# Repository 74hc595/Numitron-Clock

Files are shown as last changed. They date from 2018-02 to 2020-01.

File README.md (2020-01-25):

# IV-19 Numitron Alarm Clock

This is a digital alarm clock that uses Soviet surplus IV-19 (ИВ-19) incandescent ["numitron"](http://www.decadecounter.com/vta/tubepage.php?item=10) displays. 

**[Video overview](https://www.youtube.com/watch?v=N-rBARzu5Fk)**

## Features

The feature set is similar to that of my [Panaplex clock](https://github.com/74hc595/Panaplex-Clock):

- Six digit display (hours/minutes/seconds and month/day/year)
- Powered from a 5V USB charger
- Coin cell battery backup keeps time when unplugged
- Highly accurate oscillator; keeps time within ±3 parts per million
- Piezo beeper alarm
- Automatic leap year correction up to 2099
- Automatic daylight saving time correction (US) up to 2099
- 4-level brightness control
- Sleep mode: can be configured to keep the display blanked and only show the time for a few seconds at the press of a button

## Background

Unlike Nixie tubes, a numitron is not filled with gas and doesn't require high voltage; each segment is literally just an incandescent filament, same as you'd find in a light bulb.

They were a technological stopgap between nixie tubes and LEDs. They also seem to have been used extensively in avionics equipment. (and in the climax of the movie _WarGames_!) I remember seeing them on fuel pumps in the late 1980s.

I found these particular displays on eBay and despite their insane price (US$25 each!) I bought them because of their very uncommon [nine-segment layout](https://en.wikipedia.org/wiki/Nine-segment_display). I've only found evidence of two other people using these displays for projects—and I had to resort to a [Yandex image search](https://yandex.ru/images/search?text=ИВ-20)!

I was able to find a scan of the original Russian datasheet on [Dieter's tube data site](http://www.tube-tester.com/sites/nixie/dat_arch.htm). I've included it in this repo, along with a rough Google translation.

## Hardware

The design is fairly straightforward. Numitrons don't multiplex well, so all 60 segments are direct-driven. They don't require high voltage (I'm driving them with a 3.7V supply) so I used four [STP16CP05](https://www.mouser.com/ProductDetail/STMicroelectronics/STP16CP05MTR/?qs=sGAEpiMZZMvsUbCbgzcXuExUir1Co9YI) constant-current shift register drivers. The segments draw about 22 mA _each_—over an order of magnitude more than LED displays. Multiply that by 60, then multiply that by 3.7, and you'll find that the display draws 4.8 watts with all segments illuminated!

For the brains, I use an [NXP LPC811](https://www.nxp.com/products/processors-and-microcontrollers/arm-based-processors-and-mcus/lpc-cortex-m-mcus/lpc800-series-cortex-m0-plus-mcus/low-cost-microcontroll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)—a relatively bare-bones Arm Cortex-M0+ microcontroller.

Like the Panaplex clock, the enclosure design is an homage to the wood-grain Heathkit clocks from the 1970s, like the [GC-1005](http://tubetime.us/index.php/2012/04/). (Hi Eric!) It's made of 1/8" laser-cut walnut hardwood. The faceplate is transparent 1/8" acrylic, also laser-cut. Unlike neon/Nixie tubes, which emit a very specific wavelength of orange light, the numitron filaments give off a wide spectrum of light, so you can use any color filter you want! I made transparent red, green, and blue faceplates. The blue is best in my opinion—the digits are a deep turquoise color that I haven't been able to photograph successfully.

## Operation

There is a column of three pushbuttons on the back. From top to bottom, they are labeled `+` (Plus), `◉` (Enter), and `−` (Minus).

#### Time display

At the 26th second of even minutes, the date is shown (month/day/year, sorry rest-of-the-world) for 5 seconds. If the backup battery is failing or not present, the display will also briefly show `BAT LO`.

During time display, each button has two functions:

- **Press** `+`: change brightness
- **Hold** `+`: enter sleep mode
- **Press** `◉`: set alarm (see below)
- **Hold** `◉`: set time (see below)
- **Press** `−`: show date for 5 seconds
- **Hold** `−`: enter options menu (see below)

### Setting the time

The hours should be flashing. Use `+`/`−` to change the hour. Press `◉` to advance to the minutes and use `+`/`−` to change the minute. Pressing `◉` finalizes the time, resetting the seconds to :00 and returning you to the normal time display.

Hold `◉` to cancel and return to the normal time display. Any changes to the time are discarded.

### Setting the alarm

The letter `A.` should be flashing. Pressing `+` or `−` toggles the alarm on and off. When the alarm is active, the decimal point of the rightmost digit will illuminate.

Press `◉` to advance to the hours. Use `+`/`−` to change the hour. Press `◉` to advance to the minutes and use `+`/`−` to change the minute.

Hold `◉` to cancel and return to the normal time display. Any changes to the alarm time are discarded.

### Silencing the alarm

When the alarm is going off, hold any button to silence it.

### Alarms and loss of power

The alarm time and state are saved in battery-backed memory. If power is lost, but restored before the alarm's set time, the alarm will go off normally. If power is restored _after_ the alarm's set time, the alarm will _not_ go off.

### Options menu

Pressing `+` and `−` cycle through the menu options:

- `zzz` - turn sleep mode on/off (`Y`/`N`)
- `DATE>` - press `◉` to set date (see below)
- `A.DST` - turn automatic daylight saving time correction on/off (`Y`/`N`)
- `FONT` - switch between 9-segment font (`1`) and 7-segment font (`2`) for time/date display
- `CYCL` - turn date cycling on even minutes on/off (`Y`/`N`)
- `STYLE>` - press `◉` to change time display style (see below)
- Backup battery status: will show `BAT OK` or `BAT LO`
- Firmware version, e.g. `Ver 1.2`
- `DONE>` - press `◉` to return to normal time display

Hold `◉` to cancel and return to the normal time display.

### Setting the date

The month should be flashing. Use `+`/`−` to change the month. Press `◉` to advance to the date and use `+`/`−` to change the date. Press `◉` to advance to the year and use `+`/`−` to change the year. Press `◉` to finalize the date.

Hold `◉` to cancel and return to the menu. Any changes to the date are discarded.

### Setting the display style

Press `+` and `−` to cycle through four time display options:

- `hh.mm.ss` (hour, minute, second)
- `hh.mm` (hour and minute only)
- `h.mm a` (12-hour display with hour, minute, and AM/PM indicator. `◿`=AM, `◸`=PM)
- `hh . mm` (hour and minute only)

Press `◉` to return to the menu.

### Flashing new firmware

Cycle through menu options until the firmware version is displayed. Hold `+` to enter the bootloader. The display will show `---`. You can now connect a 5V FTDI cable and use the `lpc21isp` utility to flash a new firmware image.

To return to normal operation, disconnect and reconnect the power.

## Power considerations

The clock can draw up to 1.5A during operation. It's recommended that you use a high-quality USB power adapter (10 watts or higher), and a "28/24 AWG" USB mini-B cable.

## Version history

### Version 1.2 (March 21, 2019)

- Reduced number of brightness levels to 4.
- Added option to change the number font to one that uses a "standard" 7-segment layout which does not use the diagonal segments. Some may find this more readable.

### Version 1.1 (April 29, 2018)

- 12-hour display style added. Selectable from the `STYLE>` menu. When enabled, 12-hour format with AM/PM indicator (`◿`=AM, `◸`=PM) is used when displaying the time, setting the time, and setting the alarm.

### Version 1.0 (February 11, 2018)

- Initial release

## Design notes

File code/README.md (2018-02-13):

# IV-19 Numitron Clock Firmware

### Requirements
- GNU `arm-none-eabi-gcc` toolchain
- `lpc21isp` v1.97 (available from Homebrew on a Mac or from [GitHub](https://github.com/capiman/lpc21isp))
- 5V FTDI USB-serial cable

### To build
- Run `make`.
- Connect the FTDI cable to the 6-pin header on the clock (black wire indicated by a pointing triangle).
- Power on the clock while holding top button (SW1). Display should not illuminate.
- Run `make flash`.

### Hardware
The clock uses the [NXP LPC811](https://www.nxp.com/products/processors-and-microcontrollers/arm-based-processors-and-mcus/lpc-cortex-m-mcus/lpc800-series-cortex-m0-plus-mcus/low-cost-microcontroll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), a no-frills Arm Cortex-M0+ microcontroller with 8KB flash and 2KB RAM. Despite its limited peripheral set, (it doesn't even have an ADC) it gets the job done. I chose this chip for 3 reasons:

1. It has a serial bootloader in ROM and can be programmed with just an FTDI cable
2. The peripherals are simple enough that vendor SDK code isn't required
3. I had a couple of them lying around

The real-time clock is the [NXP PCF2129](https://www.nxp.com/products/analog/signal-chain/real-time-clocks/rtcs-with-temperature-compensation/accurate-rtc-with-integrated-quartz-crystal-for-industrial-appli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). It has a built-in temperature compensated oscillator with an advertised accuracy of ±3 ppm. Its feature set is similar to that of Maxim's high accurary real-time clocks like the [DS3234](https://www.mouser.com/ProductDetail/Maxim-Integrated/DS3234S?qs=sGAEpiMZZMuuBt6TL7D%2f6Oew70i91ENb), but it's a [third](https://www.mouser.com/ProductDetail/NXP-Semiconductors/PCF2129AT-2518?qs=sGAEpiMZZMvocn3OtlEZq6VFh71YhKpQ) of the price.

### Code notes

The driver and utility functions are written in C and the application code is C++11. 

The display state is encoded in a 64-bit integer. Since the display only has 60 segments (each digit has 10 segments; nine plus decimal point), 4 bits are unused. The mapping from bits to segments is irregular; the bit assignment was chosen to simplify the circuit layout. Each 32-bit word holds the data for 30 segments (3 digits) with 2 bits unused.

For ease of programming, application code treats the display as six 16-bit halfwords, one per digit, with the lower 10 bits mapping to segments `a` through `i` plus decimal point. The function `three_digits_packed()` converts three 16-bit values to the particular 32-bit internal representation. And it's written in assembly because I couldn't help myself. :)

SysTick is the only interrupt used. It runs at a rate of 480 Hz. On each iteration, the segment pattern is shifted out to the drivers. This handles the segment preheating and PWM dimming. 480 Hz allows for eight levels of brightness without visible flicker.

One oddity is that the display shift registers are always cleared (by shifting out 64 zeros) before shifting out the segment pattern. I was encountering a weird issue where the leftmost 3 digits would glitch out occasionally. I assumed this was due to a timing glitch, but rather than tracking down the root cause, I found that the glitch disappeared if the shift registers were zeroed first. So I hacked that up and moved on. :)

Every 8 ticks (60 Hz) the button state is read and the `/RTC_INT` line is checked. The PCF2129AT is configured to pulse `/RTC_INT` low once per second. The pin change interrupt is used to detect falling edges, but to keep the code simple and deterministic, I poll the interrupt flag rather than use the actual asynchronous interrupt.

At any time, only one "app" has control of the display. An "app" can be thought of as a state in a state machine. Each app exposes two public methods. `init()` is called when an app becomes active. `update()` is called at 60 Hz with a 32-bit bitmask of asserted input events. It returns a pointer to another app, or `NULL` if no state change is required. The methods `timeout()` and `flash_mask()` are used by the main loop to handle common logic for apps that "time out" after a period of no input and apps that want to flash portions of the display.

As much as possible, all date arithmetic is performed in binary coded decimal.

The PCF2129 does not have dedicated battery-backed SRAM for storing settings. However, since the clock doesn't need the day and weekday alarms, I can use them as 10 bits of general-purpose battery-backed storage, saving me from using a more expensive RTC or using the battery to keep the microcontroller powered while unplugged.

The SCTimer peripheral is used to generate two complementary square waves which drive the piezo beeper.

### Special thanks

Kevin Townsend for his [LPC810 base code](https://github.com/microbuilder/LPC810_CodeBase).

James Coxon for the only [reasonable SCTimer PWM example](https://github.com/jamescoxon/LPC812/blob/master/src/pwm.c) I could find online.

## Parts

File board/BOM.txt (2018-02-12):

IV-19 Numitron Clock Bill of Materials
======================================

BT1                     12mm coin cell holder, SMD, Linx BAT-HLD-012-SMT
C1, C2, C3              0.1uF multilayer ceramic capacitor, 16V or higher, 0603
C4                      1uF X7R multilayer ceramic capacitor, 16V or higher, 0603
C5                      2.2uF X7R multilayer ceramic capacitor, 16V or higher, 0603
C6                      10uF multilayer ceramic capacitor, 25V, 1206, AVX 12063C106KAT2A
C7                      10uF tantalum capacitor, 20V, 1210, AVX TAJB106K020RNJV
J101                    1x31 0.1" straight header pin
J102                    1x30 0.1" straight header pin
J201                    1x31 0.1" straight header socket
J202                    1x30 0.1" straight header socket
J204                    1x6 0.1" right-angle header pin
J205                    USB-B mini socket, straight, Amphenol UE25BE5510H
N1, N2, N3, N4, N5, N6  IV-19 numitron tube (eBay)
                        Pin sockets: Mill-Max 0327-0-15-15-34-27-10-0, qty 60
R1, R2, R3, R4, R5      910 ohm resistor, 1/8 watt, 1206
R6                      240 ohm resistor, 1/8 watt, 1206
R7                      470 ohm resistor, 1/8 watt, 1206
SW1, SW2, SW3           Tactile switch, 6mm, through hole, 13mm actuator
U1, U2, U3, U4          Display driver, ST STP16CP05MTR
U5                      Cortex-M0+ microcontroller, NXP LPC811M001JDH16J
U6                      Real-time clock, NXP PCF2129AT/2,518
U7                      3.3V LDO regulator, TI TPS70933DBVR
U8                      3A adjustable LDO regulator, TI LM1085ISX-ADJ/NOPB
Y1                      Piezo sounder, Murata PKLCS1212E2000-R1

(J203 omitted)

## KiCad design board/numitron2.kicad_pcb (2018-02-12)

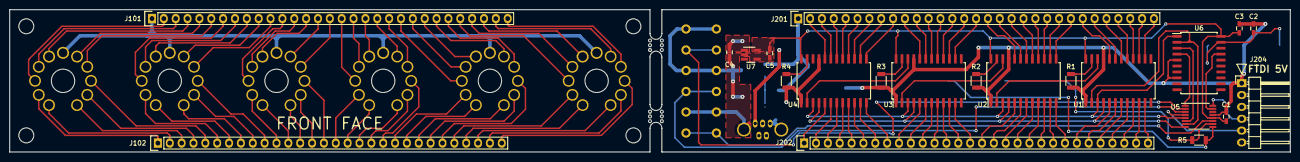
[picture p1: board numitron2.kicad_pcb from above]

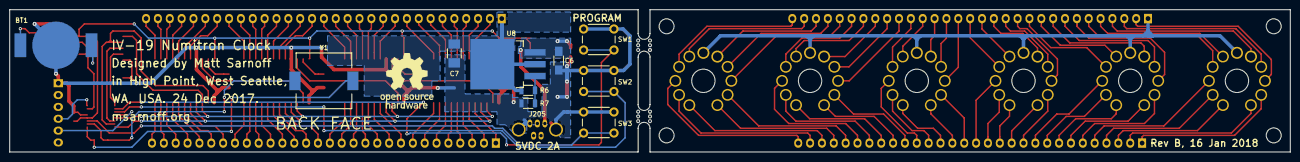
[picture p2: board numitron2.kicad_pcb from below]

Board: 2 copper layers, 274.3 x 30.5 mm, 39 parts (11 on the bottom side), 147 nets.

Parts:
BT1: CR2032; BAT-HLD-012-SMT
C1, C2, C3: 0.1uF; C_0603_HandSoldering
C4: 1uF; C_0603_HandSoldering
C5: 2.2uF; C_0603_HandSoldering
C6: 10uF; C_1206_HandSoldering
C7: 10uF; C_1210_HandSoldering
J101: CONN_01X31; Pin_Header_Straight_1x31
J102: CONN_01X30; Pin_Header_Straight_1x30
J201: CONN_01X31; Socket_Strip_Straight_1x31
J202: CONN_01X30; Socket_Strip_Straight_1x30
J204: FTDI (ISP); Pin_Header_Angled_1x06
J205: USB_OTG; UE25BE5510H
N1, N2, N3, N4, N5, N6: IV-19
R1, R2, R3, R4, R6, R7: R; R_1206
R5: 1k; R_1206
SW1, SW2, SW3: SW_Push; SW_PUSH_6mm
U1, U2, U3, U4: STP16CP05; SOIC-24W_7.5x15.4mm_Pitch1.27mm
U5: LPC811M001JDH16; TSSOP-16_4.4x5mm_Pitch0.65mm
U6: PCF2129AT; SOIC-20W_7.5x12.8mm_Pitch1.27mm
U7: TPS70933; SOT-23-5_HandSoldering
U8: LM1085ISX-ADJ/NOPB; TO-263-3Lead
Y1: PKLCS1212E2000-R1; PKLCS1212

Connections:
+3V3: C1.1, C3.1, C5.1, U1.24, U2.24, U3.24, U4.24, U5.12, U6.20, U7.5
+5V: C4.1, C6.1, J205.1, U7.1, U8.3
/1A: J101.4, N1.7
/1A': J201.4, U4.18
/1B: J101.5, N1.5
/1B': J201.5, U4.17
/1C: J102.3, N1.1
/1C': J202.3, U4.7
/1D: J102.1, N1.10
/1D': J202.1, U4.5
/1DP: J102.4, N1.2
/1DP': J202.4, U4.8
/1E: J101.2, N1.9
/1E': J201.2, U4.20
/1F: J101.3, N1.8
/1F': J201.3, U4.19
/1G: J102.5, N1.3
/1G': J202.5, U4.9
/1H: J101.6, N1.4
/1H': J201.6, U4.16
/1I: J102.2, N1.11
/1I': J202.2, U4.6
/2A: J101.9, N2.7
/2A': J201.9, U4.13
/2B: J101.10, N2.5
/2B': J201.10, U3.20
/2C: J102.8, N2.1
/2C': J202.8, U4.12
/2D: J102.6, N2.10
/2D': J202.6, U4.10
/2DP: J102.9, N2.2
/2DP': J202.9, U3.5
/2E: J101.7, N2.9
/2E': J201.7, U4.15
/2F: J101.8, N2.8
/2F': J201.8, U4.14
/2G: J102.10, N2.3
/2G': J202.10, U3.6
/2H: J101.11, N2.4
/2H': J201.11, U3.19
/2I: J102.7, N2.11
/2I': J202.7, U4.11
/3A: J101.14, N3.7
/3A': J201.14, U3.16
/3B: J101.15, N3.5
/3B': J201.15, U3.15
/3C: J102.13, N3.1
/3C': J202.13, U3.9
/3D: J102.11, N3.10
/3D': J202.11, U3.7
/3DP: J102.14, N3.2
/3DP': J202.14, U3.10
/3E: J101.12, N3.9
/3E': J201.12, U3.18
/3F: J101.13, N3.8
/3F': J201.13, U3.17
/3G: J102.15, N3.3
/3G': J202.15, U3.11
/3H: J101.16, N3.4
/3H': J201.16, U3.14
/3I: J102.12, N3.11
/3I': J202.12, U3.8
/4A: J101.19, N4.7
/4A': J201.19, U2.18
/4B: J101.20, N4.5
/4B': J201.20, U2.17
/4C: J102.18, N4.1
/4C': J202.18, U2.7
/4D: J102.16, N4.10
/4D': J202.16, U2.5
/4DP: J102.19, N4.2
/4DP': J202.19, U2.8
/4E: J101.17, N4.9
/4E': J201.17, U2.20
/4F: J101.18, N4.8
/4F': J201.18, U2.19
/4G: J102.20, N4.3
/4G': J202.20, U2.9
/4H: J101.21, N4.4
/4H': J201.21, U2.16
/4I: J102.17, N4.11
/4I': J202.17, U2.6
/5A: J101.24, N5.7
/5A': J201.24, U2.13
/5B: J101.25, N5.5
/5B': J201.25, U1.20
/5C: J102.23, N5.1
/5C': J202.23, U2.12
/5D: J102.21, N5.10
/5D': J202.21, U2.10
/5DP: J102.24, N5.2
/5DP': J202.24, U1.5
/5E: J101.22, N5.9
/5E': J201.22, U2.15
/5F: J101.23, N5.8
/5F': J201.23, U2.14
/5G: J102.25, N5.3
/5G': J202.25, U1.6
/5H: J101.26, N5.4
/5H': J201.26, U1.19
/5I: J102.22, N5.11
/5I': J202.22, U2.11
/6A: J101.29, N6.7
/6A': J201.29, U1.16
/6B: J101.30, N6.5
/6B': J201.30, U1.15
/6C: J102.28, N6.1
/6C': J202.28, U1.9
/6D: J102.26, N6.10
/6D': J202.26, U1.7
/6DP: J102.29, N6.2
/6DP': J202.29, U1.10
/6E: J101.27, N6.9
/6E': J201.27, U1.18
/6F: J101.28, N6.8
/6F': J201.28, U1.17
/6G: J102.30, N6.3
/6G': J202.30, U1.11
/6H: J101.31, N6.4
/6H': J201.31, U1.14
/6I: J102.27, N6.11
/6I': J202.27, U1.8
/LATCH: U1.4, U2.4, U3.4, U4.4, U5.8
/MISO: U5.6, U6.3
/MOSI: U1.2, U5.7, U6.2
/RX: J204.4, U5.16
/SCK: U1.3, U2.3, U3.3, U4.3, U5.5, U6.1
/SPKR1: R5.1, U5.10, Y1.1
/SPKR2: R5.2, U5.9, Y1.2
/SW1: SW1.1, U5.2
/SW2: SW2.1, U5.3
/SW3: SW3.1, U5.11
/TX: J204.5, U5.4
/VNN: J101.1, N1.6, N2.6, N3.6, N4.6, N5.6, N6.6
/VNN': C7.1, J201.1, R6.1, U8.2
/~RTC_INT: U5.15, U6.17
/~RTC_SS: U5.1, U6.4
GND: BT1.2, C1.2, C2.2, C3.2, C4.2, C5.2, C6.2, C7.2, J204.1, J205.5, J205.6, R1.2, R2.2, R3.2, R4.2, R7.2, SW1.2, SW2.2, SW3.2, U1.1, U1.21, U2.1, U2.21, U3.1, U3.21, U4.1, U4.21, U5.13, U6.5, U6.8, U7.2, U7.4
unnamed: BT1.1, C2.1, U6.19
unnamed: R1.1, U1.23
unnamed: R2.1, U2.23
unnamed: R3.1, U3.23
unnamed: R4.1, U4.23
unnamed: R6.2, R7.1, U8.1
unnamed: U1.22, U2.2
unnamed: U2.22, U3.2
unnamed: U3.22, U4.2

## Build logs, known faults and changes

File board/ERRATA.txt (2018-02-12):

Board Initial Revision Errata - February 11, 2018
=================================================

MOSI is connected to U5 pin 7, which is open-drain and not usable as a serial
output. The latest code has reassigned MOSI to U5 pin 14.

1. Cut the middle of the five traces between U5 and U6.
2. Solder a jumper wire from U5 pin 14 to U6 pin 2.

LATCH needs a pullup resistor.

1. Solder a 1.6k resistor to U6 pin 20.
2. Solder a jumper wire from the other end of the resistor to U1 pin 4.

The display board is 0.1" wider than the control board.

The mounting holes on the display board are unused.

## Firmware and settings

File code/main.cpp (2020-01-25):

#include "syscon.h"
#include "pins.h"
#include "delay.h"
#include "spi.h"
#include "beeper.h"
#include "display.h"
#include "button.h"
#include "event.h"
#include "rtc.h"
#include "app.h"

#ifdef __cplusplus
extern "C" {
#endif

#define MAIN_TICK_HZ    480
#define INPUT_POLL_HZ   60
#define INPUT_TICK_MASK ((MAIN_TICK_HZ/INPUT_POLL_HZ)-1)

static struct button b1;
static struct button b2;
static struct button b3;
static uint32_t main_loop_tick = 0;
static event_set_t events = 0;
static const App *current_app = &App_Startup; /* first app */
static const App *next_app = 0;


uint32_t flash_count = 0;
uint32_t timeout = 0;
uint32_t ticks_since_last_second = 0;

void SysTick_Handler(void)
{
  display_update();
  display_set_digit_font(rtc.settings.alt_font);

  /* Read button and RTC events */
  if ((main_loop_tick & INPUT_TICK_MASK) == 0) {
    events = (button_poll(&b1) << BTN1_EV_SHIFT) |
             (button_poll(&b2) << BTN2_EV_SHIFT) |
             (button_poll(&b3) << BTN3_EV_SHIFT) |
             (rtc_poll()       << RTC_EV_SHIFT);

    if (events & RTC_SECOND) {
      rtc_get_state(&rtc);
      /* At 02:00:00, do daylight saving time check */
      if (rtc.time.seconds == 0x00 && rtc.time.minutes == 0x00 && rtc.time.hours == 0x02) {
        rtc_dst_transition_check(&rtc);
      }
      ticks_since_last_second = 0;
    } else {
      ticks_since_last_second++;
    }

    /* Button events restart the app timeout if there is one */
    if (events & (BTN1_ANY|BTN2_ANY|BTN3_ANY)) {
      timeout = current_app->timeout();
    }
    if (timeout > 0) {
      timeout--;
      if (timeout == 0) {
        events |= EV_TIMEOUT;
      }
    }

    /* Add flash events */
    events |= (((flash_count >> 3) & 0b11) << 28);

    /* Run current app */
    next_app = current_app->update(events);

    /* Override next app if alarm is going off */
    if (events & RTC_ALARM) {
      next_app = &App_AlarmGoingOff;
    }

    /* Take care of flashing */
    if (events & FLASH) {
      /* If bit 7 in the flash mask is set, preserve decimal points. */
      uint8_t flashmask = current_app->flash_mask();
      display_buffer_and_digits(flashmask, (flashmask & 0x80) ? sP : 0);
    }

    /* Update display */
    display_buffer_commit();

    /* Transition to next app if instructed */
    if (next_app && (next_app != current_app)) {
      current_app = next_app;
      current_app->init();
      current_app->update(EV_INITIAL);
      timeout = current_app->timeout();
    }

    flash_count++;
  }

  main_loop_tick++;
}


int main(void)
{
  syscon_enable_clocks(CLK_GPIO|CLK_SWM|CLK_MRT|CLK_SPI0|CLK_SCT);
  syscon_reset_peripherals(RST_GPIO|RST_MRT|RST_SPI0|RST_SCT);
  pins_init();
  beeper_init();
  spi_init(LPC_SPI0);
  display_init();
  button_init(&b1, PIN_SW1);
  button_init(&b2, PIN_SW2);
  button_init(&b3, PIN_SW3);
  rtc_init();
  rtc_get_state(&rtc);
  rtc_dst_transition_check(&rtc);
  SysTick_Config(__SYSTEM_CLOCK/MAIN_TICK_HZ);
  while (1) { __WFI(); }
}

#ifdef __cplusplus
}
#endif

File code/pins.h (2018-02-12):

#ifndef PINS_H_
#define PINS_H_
#ifdef __cplusplus
extern "C" {
#endif

#include "LPC8xx.h"

/* Pin configuration:
  1	   SPI0_SSEL  (/RTC_SS) Slave Select for SPI0.
  2    PIO0_12    (SW1) General purpose digital input/output pin.
  3    PIO0_5     (SW2) General purpose digital input/output pin.
  4    U0_TXD     Transmitter output for USART0.
  5    SPI0_SCK   Serial clock for SPI0.
  6    SPI0_MISO  Master In Slave Out for SPI0.
  7    PIO0_11    (unused) General purpose digital input/output pin.
  8    PIO0_10    (LATCH) General purpose digital input/output pin.
  9    CTOUT_1    (SPKR2) SCT output 1.
  10   CTOUT_0    (SPKR1) SCT output 0.
  11   PIO0_8     (SW3) General purpose digital input/output pin.
  12   VDD        VDD
  13   VSS        VSS
  14   SPI0_MOSI  Master Out Slave In for SPI0.
  15   PIO0_6     (/RTC_INT) General purpose digital input/output pin.
  16   U0_RXD     Receiver input for USART0.
*/
#define PIN_nRTC_SS   13
#define PIN_SW1       12
#define PIN_SW2       5
#define PIN_SCK       3
#define PIN_MISO      2
#define PIN_LATCH     10
#define PIN_SPKR2     1
#define PIN_SPKR1     9
#define PIN_MOSI      7
#define PIN_SW3       8
#define PIN_nRTC_INT  6

/* this is an AVR-GCC idiom */
#define _BV(n)            (1UL<<(n))

#define pins_input(bits)  LPC_GPIO_PORT->DIR0 &= ~(bits)
#define pins_output(bits) LPC_GPIO_PORT->DIR0 |=  (bits)
#define pins_high(bits)   LPC_GPIO_PORT->SET0 =   (bits)
#define pins_low(bits)    LPC_GPIO_PORT->CLR0 =   (bits)

#define pin_input(p)      pins_input(_BV(p))
#define pin_output(p)     pins_output(_BV(p))
#define pin_high(p)       pins_high(_BV(p))
#define pin_low(p)        pins_low(_BV(p))

void pins_init(void);

#ifdef __cplusplus
}
#endif
#endif

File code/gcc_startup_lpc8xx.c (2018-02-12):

//
// gcc startup for LPC810
// Kamal Mostafa <kamal@whence.com>
//
// License: mixed
// - simple crt0 and statically allocated stack (Kamal Mostafa; Public Domain)
// - Note: empty boilerplate ISR routines from cr_startup_lpc8xx.c
//


#if defined (__USE_CMSIS)
#include "LPC8xx.h"
#endif

//*****************************************************************************
//
// Allocated stack space
//
//*****************************************************************************
#define STACKSIZE 64

static unsigned int StackMem[STACKSIZE];
#define _pStackTop ((void *)((unsigned int)StackMem + sizeof(StackMem)))

//*****************************************************************************

#define WEAK __attribute__ ((weak))
#define ALIAS(f) __attribute__ ((weak, alias (#f)))

//*****************************************************************************
//
// Forward declaration of the default handlers. These are aliased.
// When the application defines a handler (with the same name), this will
// automatically take precedence over these weak definitions
//
//*****************************************************************************

WEAK void ResetISR(void);
WEAK void NMI_Handler(void);
WEAK void HardFault_Handler(void);
WEAK void SVC_Handler(void);
WEAK void PendSV_Handler(void);
WEAK void SysTick_Handler(void);
WEAK void IntDefaultHandler(void);

//*****************************************************************************
//
// Forward declaration of the specific IRQ handlers. These are aliased
// to the IntDefaultHandler, which is a 'forever' loop. When the application
// defines a handler (with the same name), this will automatically take
// precedence over these weak definitions
//
//*****************************************************************************
void SPI0_IRQHandler(void) ALIAS(IntDefaultHandler);
void SPI1_IRQHandler(void) ALIAS(IntDefaultHandler);
void UART0_IRQHandler(void) ALIAS(IntDefaultHandler);
void UART1_IRQHandler(void) ALIAS(IntDefaultHandler);
void UART2_IRQHandler(void) ALIAS(IntDefaultHandler);
void I2C_IRQHandler(void) ALIAS(IntDefaultHandler);
void SCT_IRQHandler(void) ALIAS(IntDefaultHandler);
void MRT_IRQHandler(void) ALIAS(IntDefaultHandler);
void CMP_IRQHandler(void) ALIAS(IntDefaultHandler);
void WDT_IRQHandler(void) ALIAS(IntDefaultHandler);
void BOD_IRQHandler(void) ALIAS(IntDefaultHandler);
void WKT_IRQHandler(void) ALIAS(IntDefaultHandler);
void PININT0_IRQHandler(void) ALIAS(IntDefaultHandler);
void PININT1_IRQHandler(void) ALIAS(IntDefaultHandler);
void PININT2_IRQHandler(void) ALIAS(IntDefaultHandler);
void PININT3_IRQHandler(void) ALIAS(IntDefaultHandler);
void PININT4_IRQHandler(void) ALIAS(IntDefaultHandler);
void PININT5_IRQHandler(void) ALIAS(IntDefaultHandler);
void PININT6_IRQHandler(void) ALIAS(IntDefaultHandler);
void PININT7_IRQHandler(void) ALIAS(IntDefaultHandler);

//*****************************************************************************
//
// The vector table.
// This relies on the linker script to place at correct location in memory.
//
//*****************************************************************************
extern void (* const g_pfnVectors[])(void);
__attribute__ ((section(".isr_vector")))
void (* const g_pfnVectors[])(void) = {
	// Core Level - CM0plus
    _pStackTop, //&_vStackTop,		// The initial stack pointer
    ResetISR,				// The reset handler
    NMI_Handler,			// The NMI handler
    HardFault_Handler,			// The hard fault handler
    0,					// Reserved
    0,					// Reserved
    0,					// Reserved
    0,					// Reserved
    0,					// Reserved
    0,					// Reserved
    0,					// Reserved
    SVC_Handler,			// SVCall handler
    0,					// Reserved
    0,					// Reserved
    PendSV_Handler,			// The PendSV handler
    SysTick_Handler,			// The SysTick handler

	// Chip Level - LPC8xx
    SPI0_IRQHandler,                         // SPI0 controller
    SPI1_IRQHandler,                         // SPI1 controller
    0,                                       // Reserved
    UART0_IRQHandler,                        // UART0
    UART1_IRQHandler,                        // UART1
    UART2_IRQHandler,                        // UART2
    0,                                       // Reserved
    0,                                       // Reserved
    I2C_IRQHandler,                          // I2C controller
    SCT_IRQHandler,                          // Smart Counter Timer
    MRT_IRQHandler,                          // Multi-Rate Timer
    CMP_IRQHandler,                          // Comparator
    WDT_IRQHandler,                          // PIO1 (0:11)
    BOD_IRQHandler,                          // Brown Out Detect
    0,                                       // Reserved
    WKT_IRQHandler,                          // Wakeup timer
    0,                                       // Reserved
    0,                                       // Reserved
    0,                                       // Reserved
    0,                                       // Reserved
    0,                                       // Reserved
    0,                                       // Reserved
    0,                                       // Reserved
    0,                                       // Reserved
    PININT0_IRQHandler,                      // PIO INT0
    PININT1_IRQHandler,                      // PIO INT1
    PININT2_IRQHandler,                      // PIO INT2
    PININT3_IRQHandler,                      // PIO INT3
    PININT4_IRQHandler,                      // PIO INT4
    PININT5_IRQHandler,                      // PIO INT5
    PININT6_IRQHandler,                      // PIO INT6
    PININT7_IRQHandler,                      // PIO INT7

}; /* End of g_pfnVectors */


//*****************************************************************************
// Reset entry point for your code.
// Sets up a simple C runtime environment.
//*****************************************************************************

extern unsigned int _etext;
extern unsigned int _data;
extern unsigned int _edata;
extern unsigned int _bss;
extern unsigned int _ebss;
extern int main(void);

// Simple gcc-compatible C runtime init
static inline void
crt0(void)
{
    unsigned int *src, *dest, *dend;
    // copy the data section
    src  = (unsigned int *)(&_etext);
    dest = (unsigned int *)(&_data);
    dend = (unsigned int *)(&_edata);
    while (dest < dend)
	*(dest++) = *(src++);
    // blank the bss section
    dest = (unsigned int *)(&_bss);
    dend = (unsigned int *)(&_ebss);
    while (dest < dend)
	*(dest++) = 0;
}

__attribute__ ((section(".after_vectors")))
void
ResetISR(void)
{
#ifdef __USE_CMSIS
    SystemInit();
#endif
    crt0();
    main();
    while (1) ;	// hang if main returns
}
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

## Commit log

2018-02-12 initial import
    [numitron2.kicad_pcb, numitron2.sch]
2018-02-12 add bill of materials
    [numitron2.sch]
2018-02-12 add IV-19 tube data
2020-01-25 Version 1.2
    - reduce brightness levels to 4
    - add option to switch between 9-segment and 7-segment font
